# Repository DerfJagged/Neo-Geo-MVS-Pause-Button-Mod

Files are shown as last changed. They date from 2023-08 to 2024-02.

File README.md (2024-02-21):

# Neo Geo MVS Pause Button Mod v1.1
A simple mod to add pause button functionality to a Neo Geo MVS board.

Created by Derf of [ConsoleMods.org](https://www.consolemods.org/wiki/Main_Page).

Massive thanks to [12voltman](https://github.com/12voltman?tab=repositories) as it wouldn't have been possible without his help!

 

# Concept and Demo

The Neo Geo MVS does not normally support pausing of games through regular controls. However, (all?) games support a special pause mode when DIP switch #8 is flipped to the ON position during gameplay. This is a graceful pause, as background animations and sound generally continue playing. This mod simply allows you to use a dedicated button on your controller or control panel to electrically toggle this DIP switch. In short, this is a momentary-to-toggle switch board.

Note that this has only been test fit to sit flush on a MV-1AX motherboard. If you install this mod on a different motherboard, please let us know if it sits flush and we can note that here.

Click the image below to see a demo of the mod in action.

Neo Geo MVS Pause Button Mod (https://www.youtube.com/watch?v=1Y2-J27g2OU "Neo Geo MVS Pause Button Mod Demo")

# Manufacturing

* Feel free to remove all silkscreen except "ConsoleMods.org".
* 1.0mm thickness recommended.

# Parts

([Shopping cart containing the items below](https://www.digikey.com/en/mylists/list/QAYD25AZV5))

* One AIP74LVC2G14GC363 or equivalent SOT-363 dual inverter Schmitt trigger (INV).
* One SN74LVC1G175DCKR or equivalent SOT-363 flip flop (FLP).
* One MCP130T-315I/TT or equivalent SOT-23-3 chip for Power on Reset (POR).
* One 1kΩ resistor, preferably 0603 size (R1).
* One 10kΩ resistor, preferably 0603 size (R2).
* One 150Ω resistor, preferably 0603 size (R3).
* Two 100nF (0.1µF) capacitors, preferably 0603 size (C1 and C2).

# Installation

1. Assemble pause button PCB. Positions are marked on the board as described in the parts list.
2. Place PCB onto motherboard and align with DIP switch #8 and solder into place. <br> 
3. Solder a wire from a 5V source (such as the "C" pad marked in the picture below or any pad connected to it) to the 5V pad on the PCB.
4. Solder a wire from your desired button to act as the pause button to the SEL pad on the PCB. The suggested button is the Player 1 Select button marked in an image below. Multiple buttons can be wired to the SEL pad at once.
    - For a MV-1C: <br> 
    - For a MV-1AX: <br> 
7. Press the pause button during gameplay to pause the game!
    - If UniBIOS is installed, you will need to first press Select to pause the system, then hold Start and press Select to access the UniBIOS menu.

# Schematic



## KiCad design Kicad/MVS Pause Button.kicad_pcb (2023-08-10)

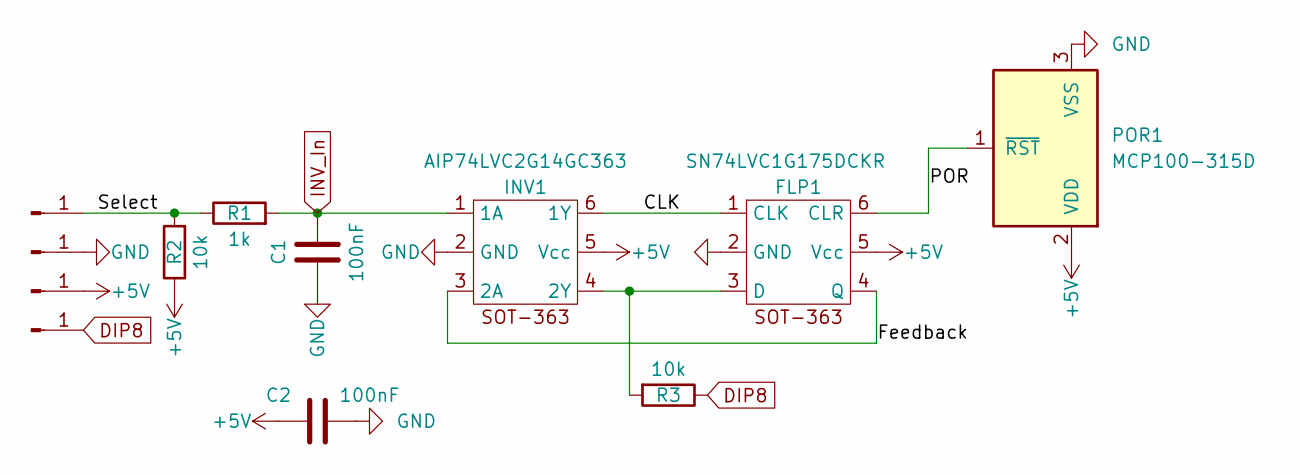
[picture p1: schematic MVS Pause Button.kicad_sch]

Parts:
C1, C2: 100nF; C_0603_1608Metric_Pad1.08x0.95mm_HandSolder
FLP1: SN74LVC1G175DCKR; SOT-363_SC-70-6_Handsoldering
INV1: AIP74LVC2G14GC363; SOT-363_SC-70-6_Handsoldering
J1, J3: Conn_01x01_Male; TestPoint_Pad_2.0x2.0mm
J2, J4: Conn_01x01_Male; TestPoint_THTPad_D2.5mm_Drill1.2mm
POR1: MCP100-315D; SOT-23_Handsoldering
R1: 1k; R_0603_1608Metric_Pad0.98x0.95mm_HandSolder
R2, R3: 10k; R_0603_1608Metric_Pad0.98x0.95mm_HandSolder

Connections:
+5V: C2.1, FLP1.5 (Vcc), INV1.5 (Vcc), J3.1, POR1.2 (VDD), R2.1
/CLK: FLP1.1 (CLK), INV1.6 (1Y)
/Feedback: FLP1.4 (Q), INV1.3 (2A)
/POR: FLP1.6 (CLR), POR1.1 (~RST)
/Select: J1.1, R1.1, R2.2
DIP8: J4.1, R3.1
GND: C1.1, C2.2, FLP1.2 (GND), INV1.2 (GND), J2.1, POR1.3 (VSS)
INV_In: C1.2, INV1.1 (1A), R1.2
unnamed: FLP1.3 (D), INV1.4 (2Y), R3.2

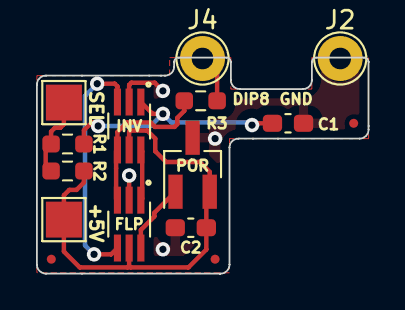
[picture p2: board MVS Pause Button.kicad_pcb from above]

Board: 2 copper layers, 18.4 x 12.0 mm, 12 parts (0 on the bottom side), 9 nets.

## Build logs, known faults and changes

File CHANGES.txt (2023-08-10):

Version 1.1:
- Added short protection resistor to DIP8 output (thanks Furrtek for pointing it out!)
- Silkscreen dots for pin 1 of INV and FLP
- Standardized silkscreen
- Moved fiducials to top layer

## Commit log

2023-08-10 v1.1
    v1.1
    [MVS Pause Button-B_Cu.gbl, MVS Pause Button-B_Mask.gbs, MVS Pause Button-B_Paste.gbp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]
2023-08-20 Update label
    [MVS Pause Button.kicad_sch]
